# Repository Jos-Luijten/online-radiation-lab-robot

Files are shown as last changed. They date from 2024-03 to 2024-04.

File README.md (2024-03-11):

# online-radiation-lab-robot
 An real world robot that receives orders from online users of a website to take measurements of radioactive samples.

## global setup
An single board computer(SBC) hosts an website on which users can create a new task for the robot to perform. The user can chose from a few radioactive samples, absorbers, measurement distance and measurement time. When user is finished and sends his task, it will be added to a queue in a MySQL database.

on the SBC runs a program that continuously checks the queue and picks the next task to execute. it will steer and direct all the motors in preparation for the measurement. After which it will start the radiation counter and reads out the result. 

the result is then saved back in to the database, completing the task.
and the website can display the result, or the number of the queued tasks.

an webcam records a live stream witch is connected to the SBC which will be visible on the hosted website.

## assignment from university of Utrecht,
This folder contains the original Assignment description (wishes, demands and intent).

## design and code controlling sensors and actuators
This folder contains the code on the SBC that continuously checks the queue in the database for tasks

## design and code of MySQL database
This folder contains the MySQL database design

## design and models of mechanics
This folder contains the step files of the physical objects and the Autodesk fusion 360 project files
all parts exported in 3 formats:
- .f3d fusion 360 archive
- .ipt inventor 2021 files
- .stp or .step STEP files

## design and code of website
This folder contains the htdoc's. such as: html, php, css and javascript code 

## operating system robot
This folder contains a copy of the operating system of the SBC. 
And a document containing explanation on the installed software and setup of the system.
Depending on the SBC, probably a type of L.A.M.P system

## parts and datasheets used in robot
This folder contains the lists of materials that were used, and their datasheets

# credits
Thanks to the "University of Utrecht" in the Netherlands, whom subsidised the project and provided the assignment.
In particular [Ing. L. van Leeuwen](https://www.uu.nl/medewerkers/LvanLeeuwen) whom aided us in this project.

Thanks to "[Spectrum Techniques](https://www.spectrumtechniques.com/)" whom cooperated whit us to control the ST365 Radiation counter externally over USB.
In particular [Rod Taylor]() whom provided the needed guiding document to do so.

Thanks to my students whom created the website, database and motor control as part of an high school research project.
O. Kaufmann and J. Wansink 

# License and copyright
We invoke GNU GENERAL PUBLIC LICENSE Version 3, 29 June 2007

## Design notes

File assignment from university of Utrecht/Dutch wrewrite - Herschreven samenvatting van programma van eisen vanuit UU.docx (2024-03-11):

# Programma van Eisen vanuit UU

# Doel:

Op middelbare scholen bieden we practica aan met radioactieve bronnen. We bezoeken ze met gespecialiseerde apparatuur en 22 verschillende practica waaruit studenten kunnen kiezen. Vaak zijn deze practica verplicht omdat ze in de PTA van de school zijn opgenomen. We bezoeken een school echter maar één keer per schooljaar, dus als een leerling afwezig is, hebben ze een probleem.

Daarom willen we graag een proefopstelling waar studenten op afstand toegang toe hebben. Zodat leerlingen samen met docenten deze proeven in eigen tijd kunnen inhalen. We gebruiken nu zo'n opstelling, maar die staat op een Australische universiteit, dus als er iets niet werkt, kunnen we er niets aan doen. Daarnaast voldoet de setup niet helemaal aan onze wensen.

# Veiligheid:

Een ander aandachtspunt zijn de radioactieve bronnen. Houd er bij het ontwerpen van deze opstelling rekening mee dat we voor stralingsveiligheid een regel volgen die ALARA heet, As Low As Reasonably Achievable. Dit betekent dat er een goede afscherming van de radioactieve stoffen moet zijn, zoals het afdekken van de bronnen wanneer deze niet worden gebruikt. Ze mogen ook geen invloed hebben op metingen van andere bronnen, wat een probleem kan zijn bij gebruik van een gamma-emitterende bron.

Er zal gewerkt worden met alfa-, bèta- en gamma- emitterende bronnen. Door de bèta emissie, moet er opgelet worden dat er geen bremsstrahlung (remstraling) ontstaat in metalen. Optie om eerst alfa en bèta af te vangen met een andere tussenstof, mogelijk perspex

# Gegeven budget:

Max 2000 euro

# Gebruikers eisen:

- Gelet op stralingsveiligheid, een afscherming van de bronnen met minimaal 6mm perspex.
- Op 10 cm van de ‘verpakking’ mag het dosistempo maximaal 1 microSievert per uur zijn.
- Het veranderen van radioactieve bron, selecteer 1 uit 6 verschillende bronnen
- Verschillende tussenstoffen met verschillende diktes invoegen tussen bron en detector Ongeveer 19 verschillende opties.
- Afstand tussen bron en detector aanpassen 100mm t/m 700mm
- Meet tijd met detector instellen tot maximaal 60 seconden
- Aantal herhalingen van de meting tot een max van 300 seconden totaal
- Optioneel, een webcam toevoegen
- Optioneel, een 2e detector toevoegen
- Resultaten van een meting zijn door middel van een unieke download link op te halen. Eerder gemeten data mag niet publiekelijk beschikbaar zijn, zo voorkomen we dat leerlingen gaan ‘afkijken’.
- Aansluiten website via ethernetkabel
- Gebruiken van poort 443 (HTTPS protocol) voor hosten van website op het apparaat.

# Gegeven apparaten en materialen:

- ST365B Radiation counter.
- Potjes van perspex met radioactieve bronnen
  - Strontium 90 ,
  - Americium 241 ,
  - Cesium 137,
- Perspex plaat materiaal 10mm dik.

# Gegeven maten en bereiken:

## Plek en ruimte voor het apparaat:

- Diepte: 400mm
- Hoogte: 1000 mm

## Afstand tussen detector en bron

- Afstand tussen 100 mm en 70 mm,

## Potjes van perspex met radioactieve bronnen

- Diameter: 35mm
- Hoogte: 42,3 mm
- Hoogte: 48 mm met deksel
- Diameter bron: 15 mm

## Aluminium tussenplaatjes

- Dikte 0.2mm,
- Dikte 0.6mm,
- Dikte 1.0mm,
- Dikte 1.4mm,
- Dikte 2.0mm,
- Dikte 4.0 mm

## Perspex tussenplaatjes

1, 2, 4, 6, 8, 10, en 12 mm

## Lood tussenplaatjes

2, 4, 6, 8, 10 mm

# Bijlages

https://stralenpracticum.nl/

https://docenten.stralenpracticum.nl/

Link to the Australian setup:

https://onlinelab.space/client/radiolab/#

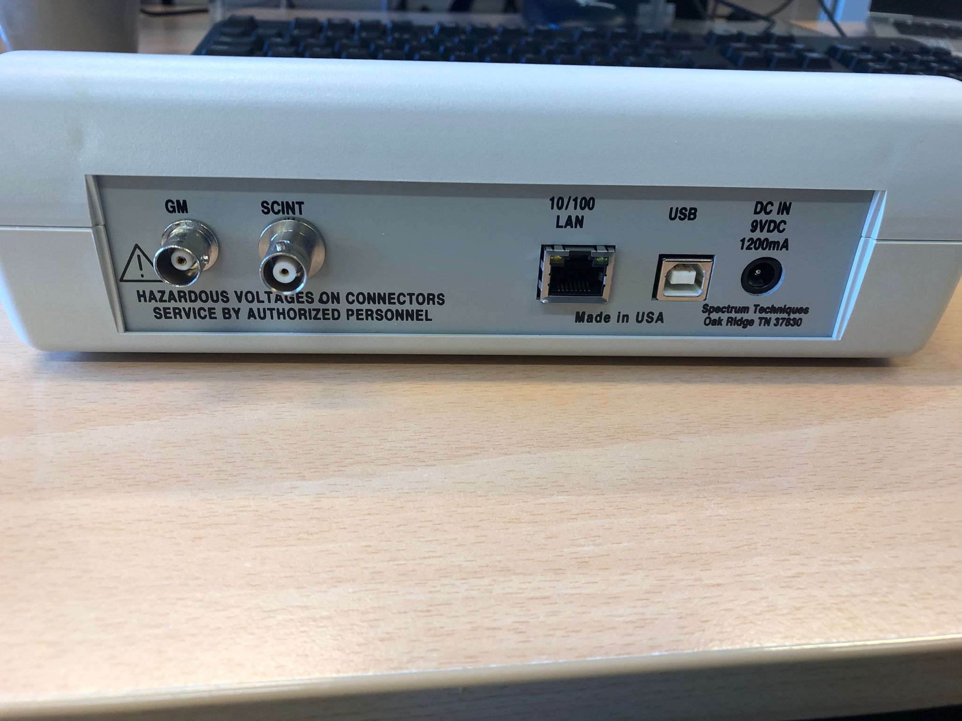
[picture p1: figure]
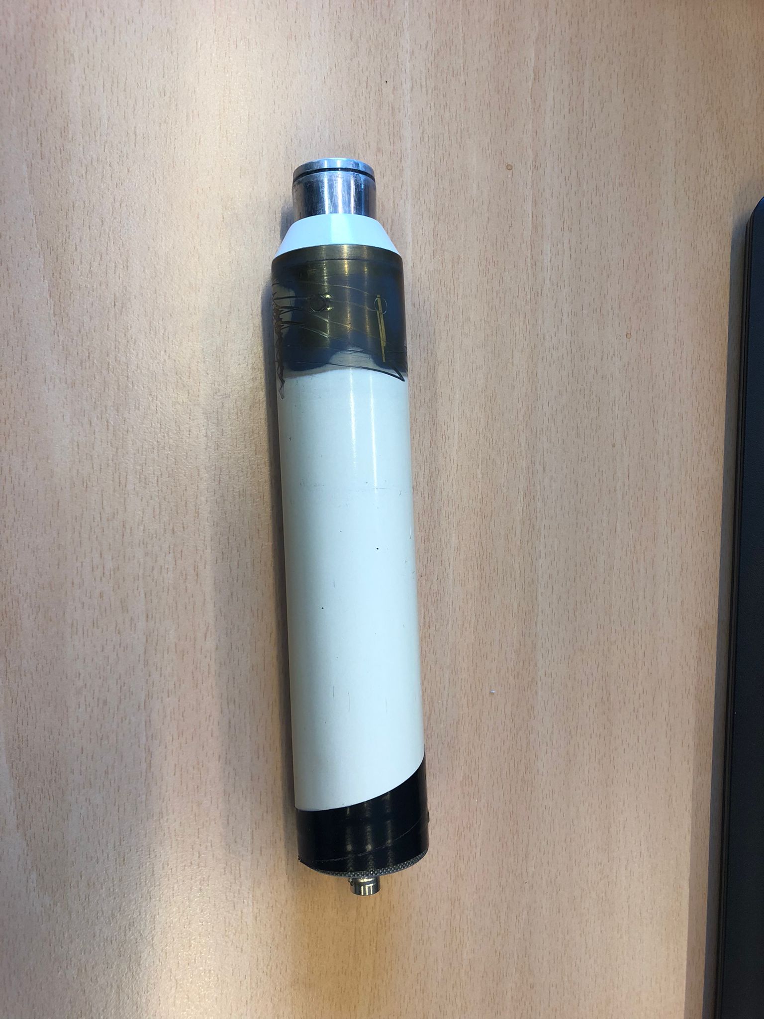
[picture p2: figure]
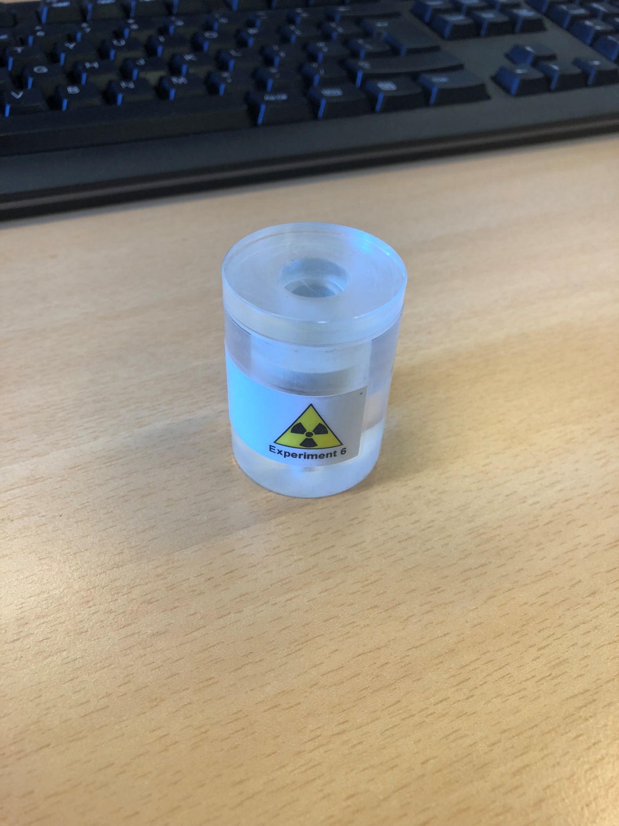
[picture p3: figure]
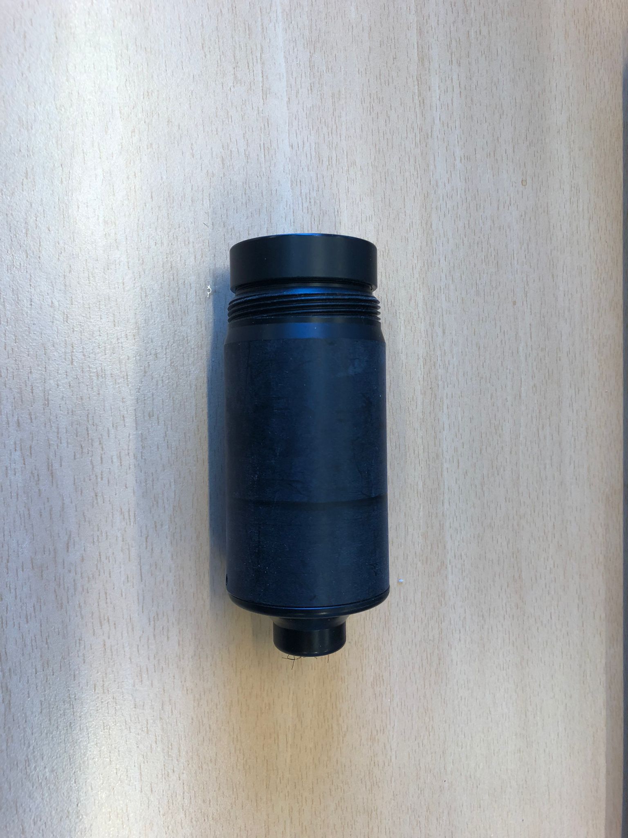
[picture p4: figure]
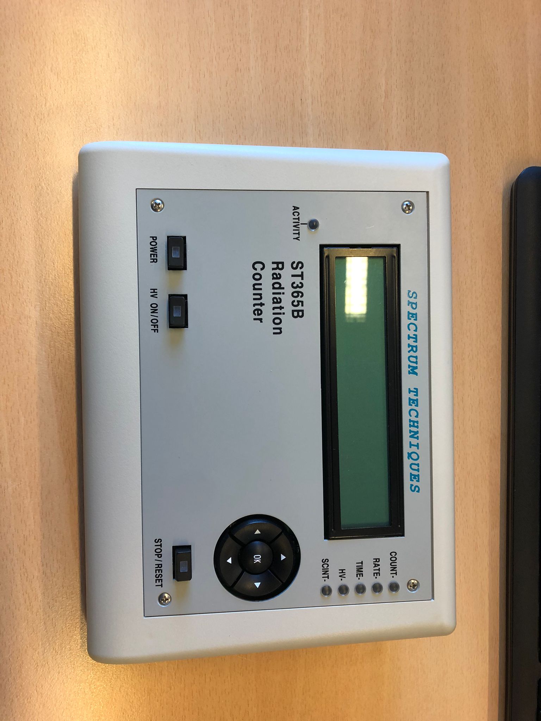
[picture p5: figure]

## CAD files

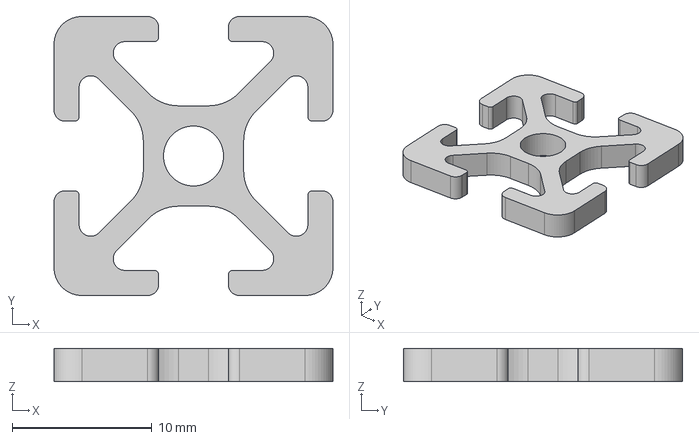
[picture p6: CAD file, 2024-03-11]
design and models of mechanics/objects from other vendors/aluminium extrusie 20x20x2mm v1.step
20.0 x 20.0 x 2.40 mm

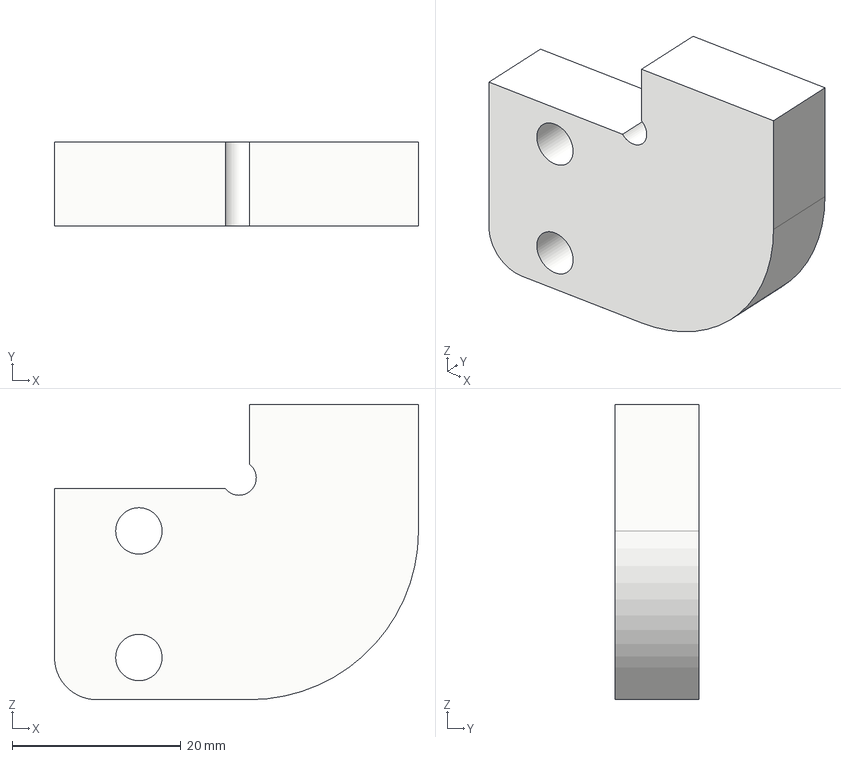
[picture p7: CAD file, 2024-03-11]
design and models of mechanics/Polymer sheet pmma models/joist1 v1.step
43.1 x 10.0 x 35.0 mm

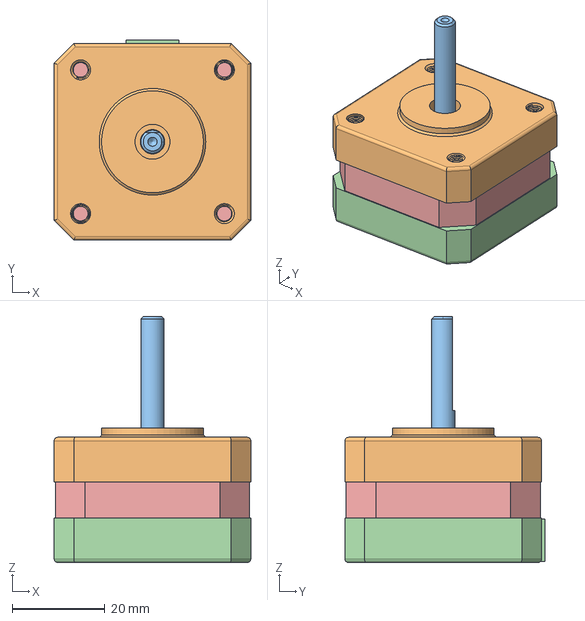
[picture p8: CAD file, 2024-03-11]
design and models of mechanics/objects from other vendors/Nema 17 klein 27mm v1.step
42.4 x 43.2 x 53.0 mm

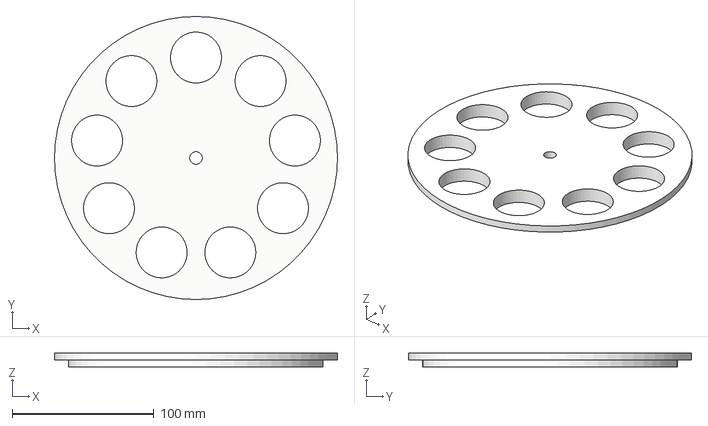
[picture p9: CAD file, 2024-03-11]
design and models of mechanics/Polymer sheet pmma models/source lid v1.step
200.0 x 200.0 x 10.0 mm

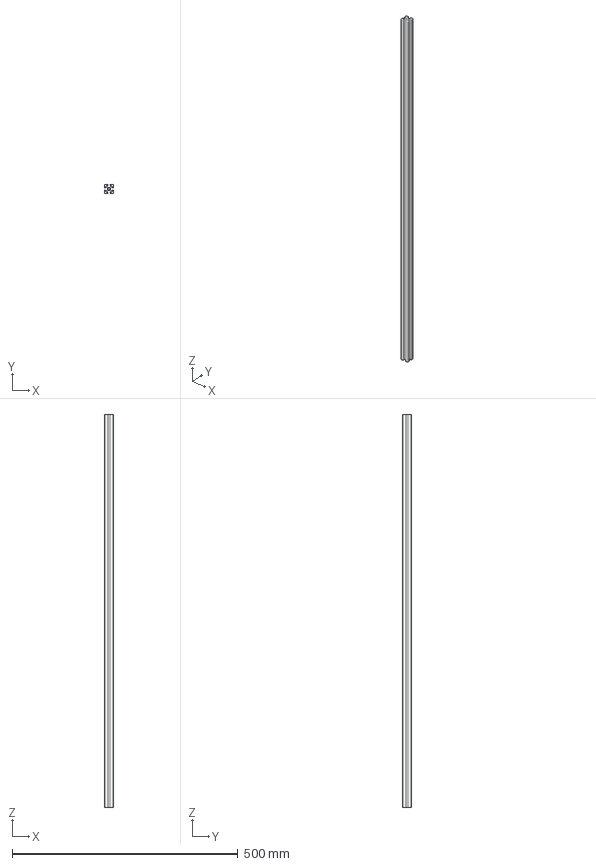
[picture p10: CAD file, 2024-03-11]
design and models of mechanics/objects from other vendors/aluminium extrusie 20x20x870mm v1.step
20.0 x 20.0 x 870.0 mm

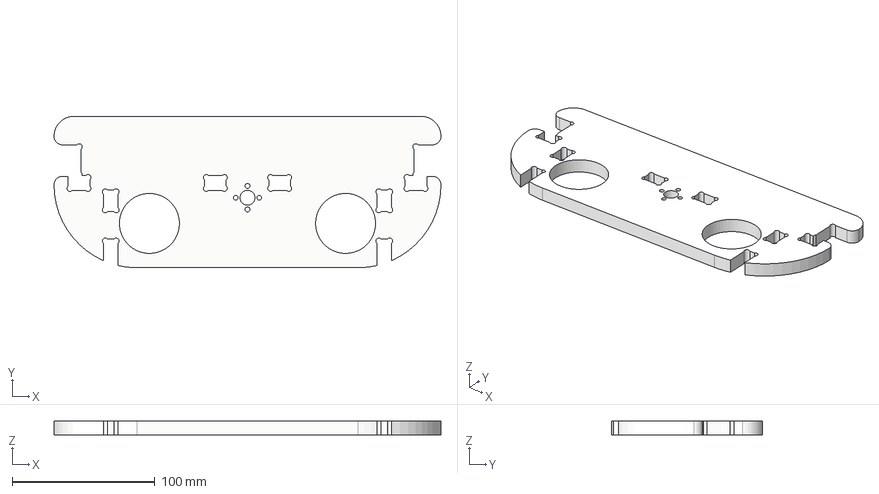
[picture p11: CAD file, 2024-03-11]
design and models of mechanics/Polymer sheet pmma models/elevator base plate v1.step
271.0 x 106.0 x 10.0 mm

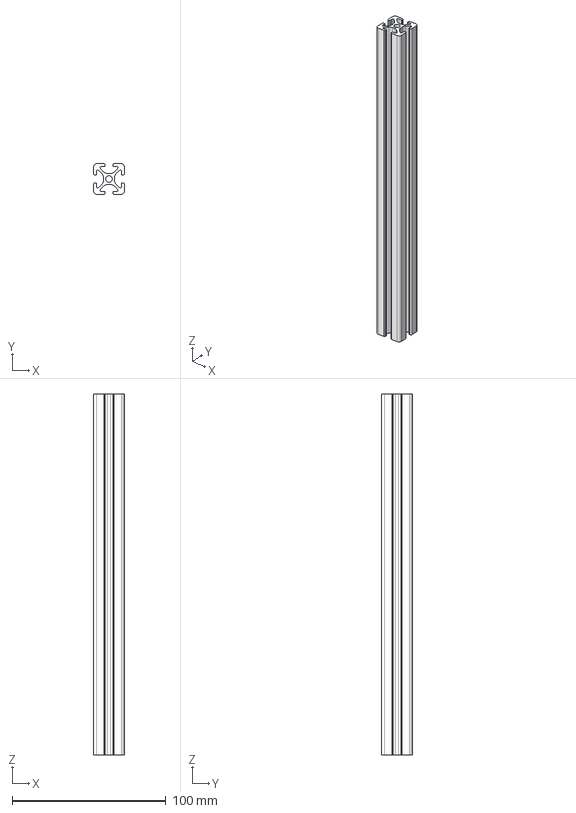
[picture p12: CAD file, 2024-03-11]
design and models of mechanics/objects from other vendors/aluminium extrusie 20x20x235mm v1.step
20.0 x 20.0 x 235.0 mm

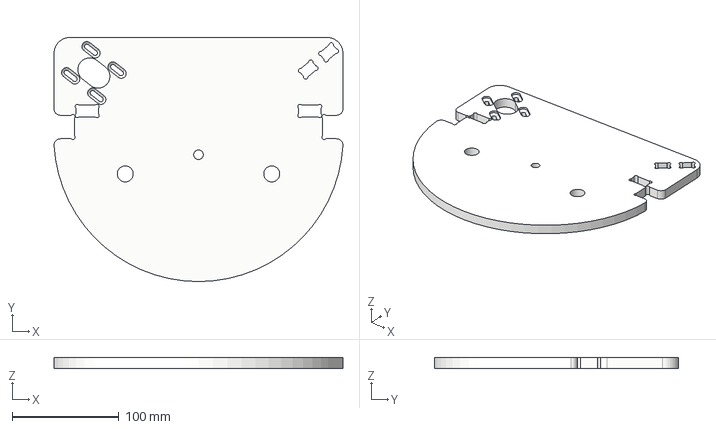
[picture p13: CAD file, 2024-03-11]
design and models of mechanics/Polymer sheet pmma models/second stage plate v1.step
271.0 x 228.9 x 10.0 mm

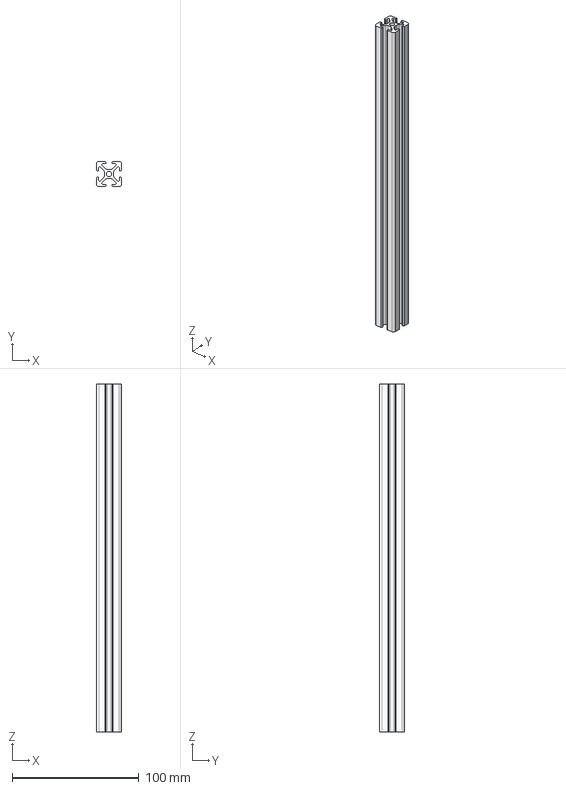
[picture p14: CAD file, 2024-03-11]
design and models of mechanics/objects from other vendors/aluminium extrusie 20x20x235+40mm v1.step
20.0 x 20.0 x 275.0 mm

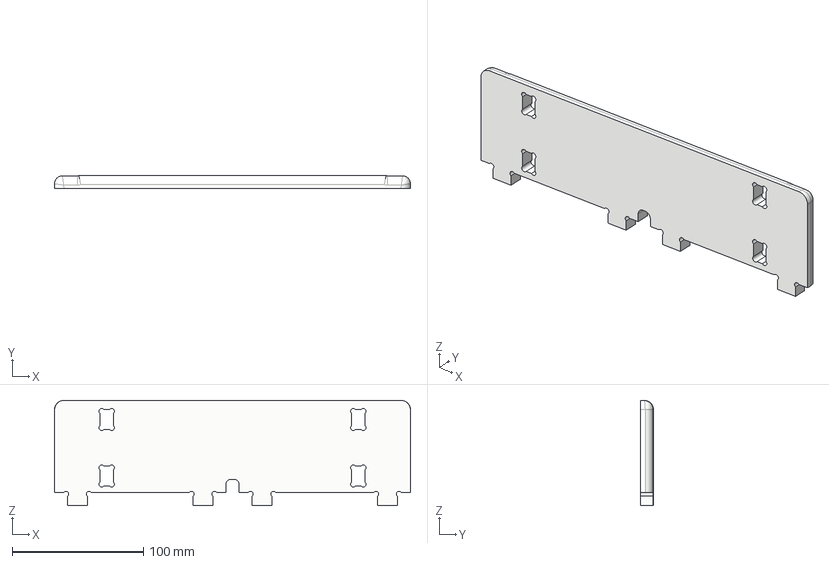
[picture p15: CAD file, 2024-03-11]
design and models of mechanics/Polymer sheet pmma models/tube buttress v1.step
271.0 x 10.0 x 80.0 mm

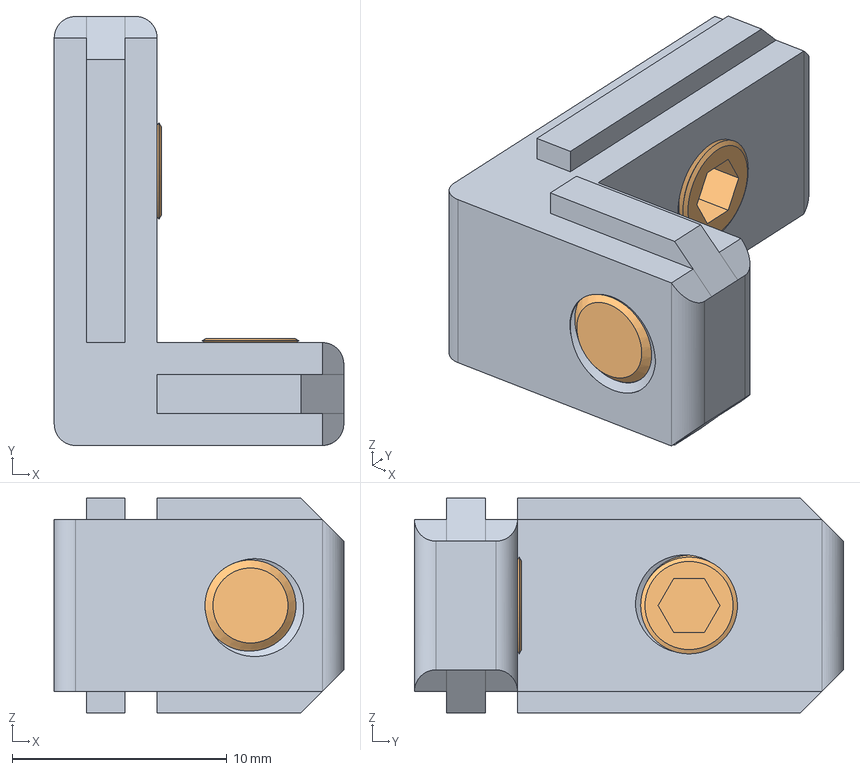
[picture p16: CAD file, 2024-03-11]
design and models of mechanics/objects from other vendors/hidden corner connector 6mm v1.step
13.5 x 20.0 x 10.0 mm
6-6-M4
socket set screw flat point_din_DIN 913 - M5 x 5-S x 2

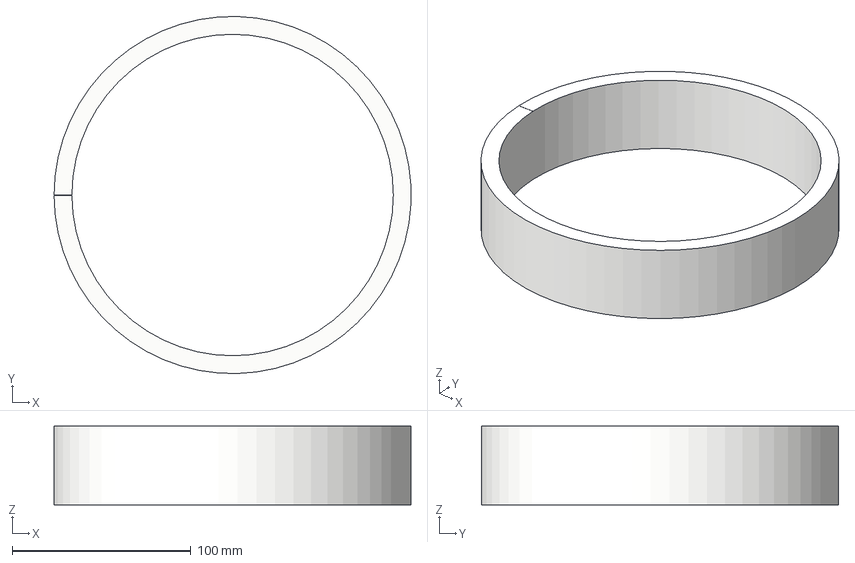
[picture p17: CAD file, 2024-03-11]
design and models of mechanics/Polymer sheet pmma models/source wall v1.step
199.9 x 199.9 x 44.0 mm

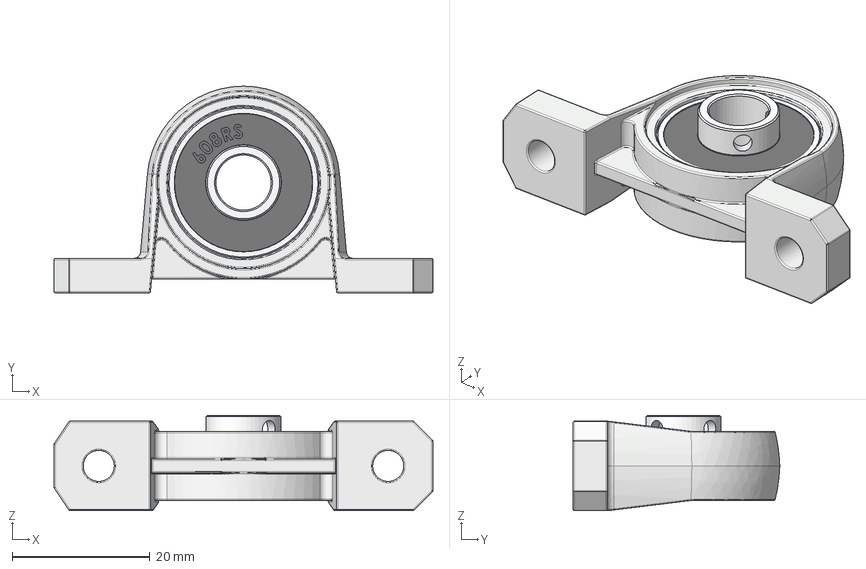
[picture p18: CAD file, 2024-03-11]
design and models of mechanics/objects from other vendors/KP08 lager as bevestiging v1.step
55.0 x 30.0 x 13.9 mm
KP08
608RS

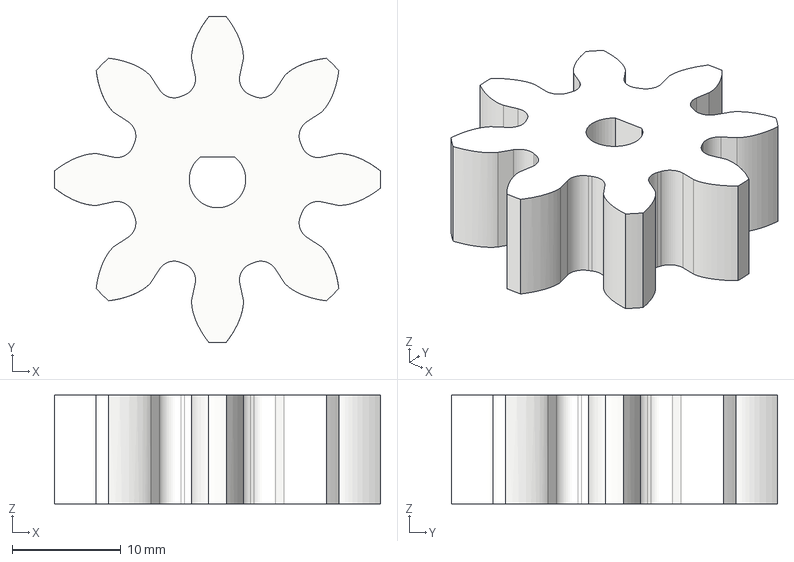
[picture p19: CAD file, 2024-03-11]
design and models of mechanics/Polymer sheet pmma models/base driver spur gear v1.step
30.0 x 30.0 x 10.0 mm

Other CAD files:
design and models of mechanics/Polymer sheet pmma models/tube binder left v1.step
design and models of mechanics/objects from other vendors/corner bracket for 20x20 rail v1.step
design and models of mechanics/Polymer sheet pmma models/base plate v1.step
design and models of mechanics/objects from other vendors/T connector for 20x20 rail v1.step
design and models of mechanics/Polymer sheet pmma models/1x - base plate.step
design and models of mechanics/Polymer sheet pmma models/1x - elevator base plate.step
design and models of mechanics/Polymer sheet pmma models/1x - intermediate pmma.step
design and models of mechanics/Polymer sheet pmma models/1x - second stage plate.step
design and models of mechanics/Polymer sheet pmma models/1x - source lid.step
design and models of mechanics/Polymer sheet pmma models/1x - tube buttress.step
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

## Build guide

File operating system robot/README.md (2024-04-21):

# Operating system installation on radiation-lab-robot
 setting up the operating system on the single board computer (SBC) and all the required programms to make it an LAMP system (Linux Apache MySql PHP).
 the SBC is connected to: 
 - power via usb-c, 
 - internet via ethernet cable to router,
 - monitor via hdmi,
 - keybord via usb,
 - mouse via usb

## os used (Linux)
debian bullseye, 
installed from file: rk3588-usb-debian-bullseye-minimal-6.1-arm64-20240311.zip

more up to date os can be found on: "[https://download.friendlyelec.com/NanoPiR6C](https://download.friendlyelec.com/NanoPiR6C)"

the OS is flashed to an micro-SD card* using win32diskimager from the "installation tools" folder.
(* it was an micro-SDHC card to be precice)
the card is inserted to the SBC, and the SBC is powered up.

when SBC is booted up, run commands to update and upgrage:
- sudo apt-get update
- sudo apt-get upgrade
- sudo reboot

## installng apache
in the commandline of the SBC use:
- sudo apt install apache2

## installing mysql (mariaDB)
in the commandline of the SBC use:
- sudo apt install mariadb-server
- sudo mysql_secure_installation 
    (removed all 'inteded for testing')

## installing php
in the commandline of the SBC use:
- sudo apt install php
- sudo apt install php-mysql

# credits
Thanks to the "University of Utrecht" in the Netherlands, whom subsidised the project and provided the assignment.
In particular [Ing. L. van Leeuwen](https://www.uu.nl/medewerkers/LvanLeeuwen) whom aided us in this project.

Thanks to "[Spectrum Techniques](https://www.spectrumtechniques.com/)" whom cooperated whit us to control the ST365 Radiation counter externally over USB.
In particular [Rod Taylor]() whom provided the needed guiding document to do so.

Thanks to my students whom created the website, database and motor control as part of an high school research project.
O. Kaufmann and J. Wansink 

# License and copyright
We invoke GNU GENERAL PUBLIC LICENSE Version 3, 29 June 2007

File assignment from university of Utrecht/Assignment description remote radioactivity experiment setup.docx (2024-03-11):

## Assignment description remote radioactivity lab

We offer practicals with radioactive sources at high schools. We visit them with specialized equipment and 22 different practicals for students to choose from. Often, these practicals are mandatory because it is written into the school’s PTA. However, we only visit a school once every school year, so when a student is absent, they have a problem.

Therefore, we would like an experiment setup that students can access remotely. We use such a setup right now, but it's located at an Australian university, so when something isn't working, we can't do anything about it. Besides that, the setup doesn’t completely cater to our needs. I've added a link to the setup below, so that you can get an idea.

What we want is an experiment setup with the following abilities:

- Changing the radioactive source
- Adding absorbers of different materials and different thicknesses (paper, perspex, aluminum, lead) between the source and the detector. This should include the following thicknesses:
  - Aluminum: 0.2, 0.6, 1.0, 1.4, 2.0, 4.0 mm
  - Perspex: 1, 2, 4, 6, 8, 10, and 12 mm
  - Lead: 2, 4, 6, 8, 10 mm
- Changing the distance between the detector and the source, height difference should be able to differ between 10 cm and 40 cm
- Setting a measurement time
- Repetition of measurements
- Optional: a webcam where the student can see the setup moving as they are changing the settings
- Optional: changing the detector type

Another point of attention are the radioactive sources. While designing this setup, keep in mind that in radiation safety, we follow a rule called ALARA, As Low As Reasonably Achievable. This means that there should be proper shielding of the radioactive materials, like covering the sources when they are not being used. They should also not influence measurements of other sources, which can be an issue when using a gamma emitting source.

The sources we will be using are:

- Sr-90 (x3)
- Am-241 (x1)
- Cs-137 (1x)

If you would like to know more about our practicals, you can visit our websites:

https://stralenpracticum.nl/

https://docenten.stralenpracticum.nl/

Link to the Australian setup:

https://onlinelab.space/client/radiolab/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

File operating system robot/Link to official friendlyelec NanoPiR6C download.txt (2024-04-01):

https://download.friendlyelec.com/NanoPiR6C

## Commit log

2024-03-11 first upload
    folders created and orderd, pre existing files placed,
    [1x - base plate.step, 1x - elevator base plate.step, 1x - intermediate pmma.step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]
2024-03-11 3d model aded
    fusion and inventor and step files aded of the robot.
    [Flexible coupler 5mm to 8mm v1.f3d, Flexible coupler 5mm to 8mm v1.ipt, Flexible coupler 5mm to 8mm v1.step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]
